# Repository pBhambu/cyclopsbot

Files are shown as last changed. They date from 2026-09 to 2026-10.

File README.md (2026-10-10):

# Cyclops Bot

An ESP32-powered robotics project controlled via Bluetooth Low Energy (BLE) using an Xbox Series X/S controller. Cyclops Bot features multi-servo continuous sweeping controls, an OLED display with custom animated face graphics, and dedicated PCB pin architecture.


robotthumnail

---

## Overview
Cyclops Bot uses an ESP32 microcontroller with an Xbox Series X/S controller over BLE using the XboxSeriesXControllerESP32_asukiaaa library. It translates controller inputs (triggers, bumpers, and buttons) into smooth position updates across 8 independent servo channels while maintaining an expressive OLED display interface.

### Key Features
- **BLE Wireless Control:** Connects to Xbox Series X/S controllers without dongles.
- **Smooth Sweep Engine:** Uses non-blocking position updates to provide smooth, continuous servo sweeps.
- **Multi-Servo Support:** Drives up to 8 independent servos with preset angle bounds and default stances.
- **Dedicated Custom PCB:** Integrates power regulation, signal breakout headers, and I2C lines directly on a custom carrier board.
- **Expressive OLED Interface:** Displays an animated eye on an I2C SSD1306 display.

---

## Hardware Architecture & Custom PCB

Cyclops Bot utilizes a custom printed circuit board (PCB) designed to consolidate component connections, isolate heavy motor current loads, and eliminate loose jumper wiring.

pcbpic

### PCB Hardware Specifications
- **Microcontroller Socket:** Dual header pins designed to fit standard 30-pin ESP32 Dev Module footprint.
- **Servo Header Rail (H1–H8):** 8 sets of 3-pin male headers (GND, VCC, Signal) wired directly to dedicated ESP32 GPIOs.
- **Power Separation Plane:** Isolated high-current 5V bus powering the servo headers separately from the ESP32 logic power rail.
- **Display Terminal:** 4-pin I2C breakout header providing 3.3V/5V, GND, SDA (GPIO 21), and SCL (GPIO 22).

---

## Components Required

### Microcontroller & Display
- **ESP32 Development Board** (e.g., ESP32 Dev Module)
- **Cyclops Bot Custom PCB**  (or breadboard/protoboard with wires)
- **0.96" SSD1306 OLED Display** (128x64 pixels, I2C interface)

### Actuators & Power
- **8x Micro Servos** (e.g., SG90, MG90S, or similar 5V servos)
- **External 5V DC Power Supply** (Minimum 3A recommended to handle servo stall currents)

### Controller
- **Xbox Series X/S Wireless Controller** (Updated with standard BLE firmware, non-controller option available)

---

## Wiring & Pin Mapping

> **Important:** Never power 8 servos directly from the ESP32's 3.3V or 5V pins. Always route the external 5V power supply to the PCB's main power screw terminal or power jack.

### Servo Pin Assignments

| PCB Servo Header | Target Motor | ESP32 GPIO Pin |
| :--- | :--- | :--- |
| **H1** | Motor 1 | **GPIO 13** |  
| **H2** | Motor 2 | **GPIO 12** | 
| **H3** | Motor 3 | **GPIO 27** | 
| **H4** | Motor 4 | **GPIO 14** | 
| **H5** | Motor 5 | **GPIO 26** |
| **H6** | Motor 6 | **GPIO 25** |
| **H7** | Motor 7 | **GPIO 33** | 
| **H8** | Motor 8 | **GPIO 32** |

### OLED Display Pin Assignments (I2C)

| SSD1306 Pin | PCB Header / ESP32 GPIO Pin |
| :--- | :--- |
| **VCC** | 3.3V / 5V Rail |
| **GND** | Common GND Plane |
| **SDA** | **GPIO 21** |
| **SCL** | **GPIO 22** |

---
## Xbox Controller Mappings

| Control Input | Action / Motion |
| :--- | :--- |
| **Left Joystick (Forward)** | Move Forward |
| **Left Joystick (Backwards)** | Move Backwards |
| **Left Joystick (Left / Right)** | Move Sideways |
| **Hold RT (Right Trigger)** | Rotate Front Right |
| **Hold RB (Right Bumper)** | Rotate Back Right |
| **Hold LT (Left Trigger)** | Rotate Front Left |
| **Hold LB (Left Bumper)** | Rotate Back Left |
| **Button A** | Attention Stance/wave|
| **Button B** | Sleep animation |

## Setup & Installation Instructions

### 1. Software Requirements
Ensure you have the **Arduino IDE** installed along with the ESP32 board package (`esp32` by Espressif Systems).

### 2. Install Required Libraries
Open the **Library Manager** in Arduino IDE (`Tools` -> `Manage Libraries...`) and install the following:

- **ESP32Servo** by Kevin Harrington
- **Adafruit_GFX** by Adafruit
- **Adafruit_SSD1306** by Adafruit
- **XboxSeriesXControllerESP32_asukiaaa** by Asuki Kono

### 3. Board & IDE Settings
Select your board configuration under **Tools**:
- **Board:** ESP32 Dev Module or similar
- **Upload Speed:** 115200

### 4. Upload & Pairing Procedure
1. Connect your ESP32 to your computer via USB and upload the sketch.
2. Open the **Serial Monitor** set to **115200 baud**.
3. Turn on your Xbox controller and hold the **Pairing Button** on top until the Xbox symbol flashes rapidly.
4. Keep the controller within close proximity to the ESP32. The Xbox button light will turn solid once successfully paired.

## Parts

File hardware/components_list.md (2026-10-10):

# Cyclops Bot Hardware - Bill of Materials (BOM)

This document details the complete hardware component list required to build and assemble the **Cyclops Bot**.

---

## Component List
For best quality and the shortest shipping time, Amazon is the best option. If you are willing to wait longer for shipping, use AliExpress or another trustworthy seller.
| Component | Category | Quantity | Notes |
| :--- | :--- | :--- | :--- |
| **ESP32 Microcontroller** | Microcontroller | 1 | ESP32 Dev Module or compatible board |
| **Servo Motors** | Actuators | 8 | SG90, MG90S, or similar 5V micro servos |
| **OLED Screen** | Display | 1 | 0.96 inch SSD1306 128x64 I2C display |
| **KCD1 Rocker Switch** | Power / Switch | 1 | Main power control switch |
| **Step-Down Converter** | Power | 1 | Buck regulator steps voltage down to stable 5V output |
| **Male Header Pins** | Connectors | 1 | 2.54mm pitch strip for PCB headers |
| **LiPo Battery** | Power | 1 | Main power source |
| **XT30 Pigtail Connector** | Power / Connectors | 1 | Male/Female battery connector lead |
| **Custom PCB** | Electronics | 1 | Cyclops Bot carrier circuit board |
| **Screws & Fasteners** | Hardware | TBD | Specific sizes and counts to be updated |

---

## Assembly Notes

- **Power Architecture:** Always ensure the **Step-Down Converter** is adjusted to output a stable **5V** before connecting it to the custom PCB or servos.
- **Header Pin Soldering:** Solder male header pins onto the PCB for all 8 servo channels (`H1` through `H8`) and the OLED display interface before mounting the ESP32.

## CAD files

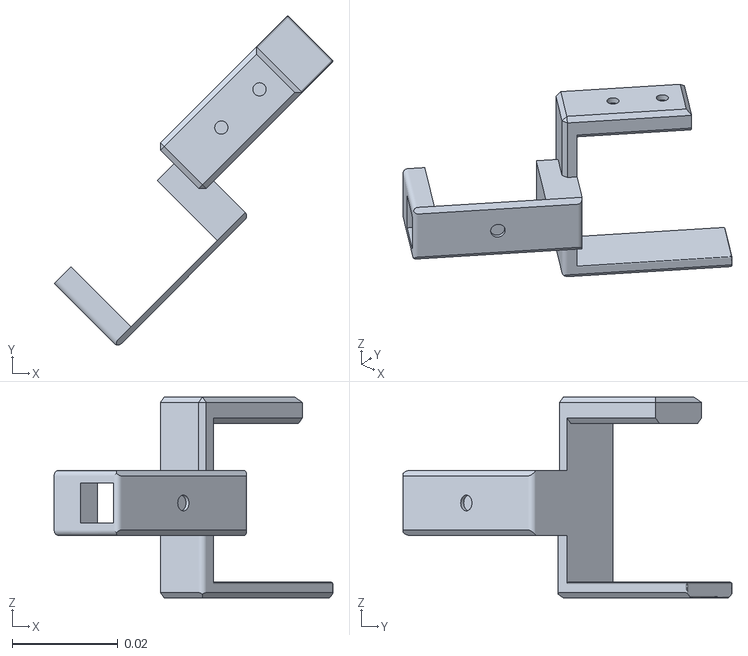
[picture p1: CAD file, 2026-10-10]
hardware/stlFiles/joint.stl
0.0526 x 0.0621 x 0.0379

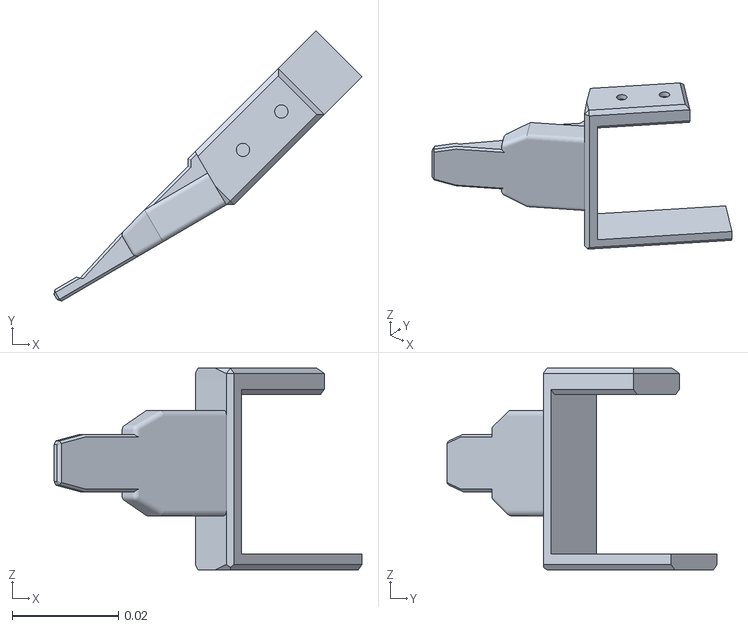
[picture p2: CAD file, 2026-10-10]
hardware/stlFiles/leg.stl
0.0579 x 0.0508 x 0.0379

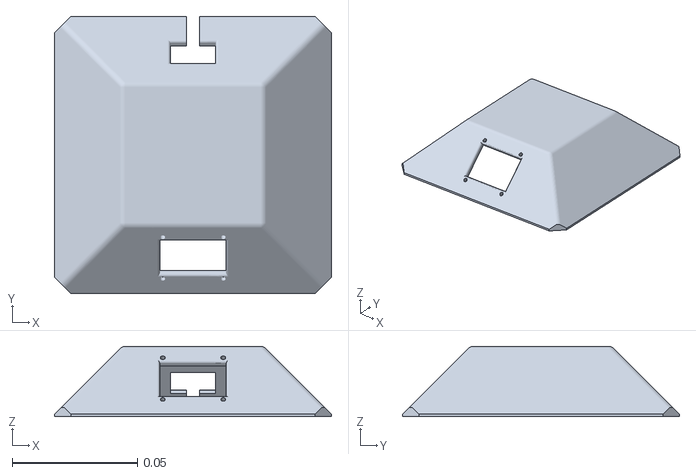
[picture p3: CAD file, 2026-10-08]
hardware/stlFiles/cover.stl
0.111 x 0.111 x 0.028

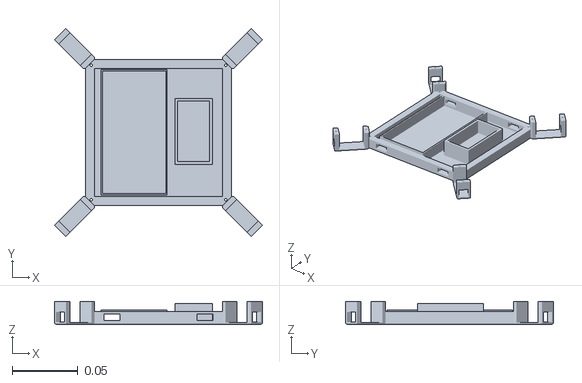
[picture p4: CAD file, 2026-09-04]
hardware/stlFiles/frame.stl
0.158 x 0.158 x 0.0177

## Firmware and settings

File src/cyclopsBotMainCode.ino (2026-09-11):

#include <Wire.h>
#include <Adafruit_GFX.h>
#include <Adafruit_SSD1306.h>
#include <ESP32Servo.h>
#include <XboxSeriesXControllerESP32_asukiaaa.hpp>

// --- OLED Setup ---
#define SCREEN_WIDTH 128
#define SCREEN_HEIGHT 64
#define OLED_RESET    -1
Adafruit_SSD1306 display(SCREEN_WIDTH, SCREEN_HEIGHT, &Wire, OLED_RESET);

const int EYE_X = 64;
const int EYE_Y = 32;

// --- ESP32 GPIO Pin Assignments ---
const int PIN_R1 = 13; // Hip Front Right
const int PIN_R2 = 12; // Hip Back Right
const int PIN_L1 = 27; // Hip Front Left
const int PIN_L2 = 14; // Hip Back Left

const int PIN_R3 = 26; // Lift Front Right
const int PIN_R4 = 25; // Lift Back Right
const int PIN_L3 = 33; // Lift Front Left
const int PIN_L4 = 32; // Lift Back Left

// --- Servo Objects ---
Servo servoR1, servoR2, servoL1, servoL2;
Servo servoR3, servoR4, servoL3, servoL4;

// --- Controller Instance ---
XboxSeriesXControllerESP32_asukiaaa::Core xboxController;

// --- Gait Parameters ---
int stepState = 0;
unsigned long lastStepTime = 0;
const int STEP_DELAY = 120; // Step speed (ms)
bool isStanding = true;

// --- OLED Cyclops Eye Renderer ---
void drawCyclopsEye(int pupilOffsetX = 0, int pupilOffsetY = 0) {
  display.clearDisplay();

  // Outer Eye White Area (Sclera)
  display.fillCircle(EYE_X, EYE_Y, 28, SSD1306_WHITE);

  // Eyelid Cutouts
  display.fillRect(EYE_X - 40, EYE_Y - 45, 80, 25, SSD1306_BLACK);
  display.fillRect(EYE_X - 40, EYE_Y + 20, 80, 25, SSD1306_BLACK);

  // Eyelid Outlines
  display.drawFastHLine(EYE_X - 30, EYE_Y - 18, 60, SSD1306_BLACK);
  display.drawFastHLine(EYE_X - 30, EYE_Y + 18, 60, SSD1306_BLACK);

  // Iris Outer Ring
  display.fillCircle(EYE_X + pupilOffsetX, EYE_Y + pupilOffsetY, 16, SSD1306_BLACK);
  display.drawCircle(EYE_X + pupilOffsetX, EYE_Y + pupilOffsetY, 17, SSD1306_WHITE);

  // Pupil Center
  display.fillCircle(EYE_X + pupilOffsetX, EYE_Y + pupilOffsetY, 10, SSD1306_WHITE);
  display.fillCircle(EYE_X + pupilOffsetX, EYE_Y + pupilOffsetY, 8, SSD1306_BLACK);

  // Catchlight Glint
  display.fillRect(EYE_X + pupilOffsetX - 4, EYE_Y + pupilOffsetY - 5, 3, 3, SSD1306_WHITE);

  display.display();
}

// --- Default Stances ---
void standUp() {
  // Hips to Neutral (Side - 90°)
  servoR1.write(90);
  servoR2.write(90);
  servoL1.write(90);
  servoL2.write(90);

  // Lifts facing DOWN
  servoR3.write(180); // R3 Down
  servoR4.write(0);   // R4 Down
  servoL3.write(0);   // L3 Down
  servoL4.write(180); // L4 Down
  
  isStanding = true;
  drawCyclopsEye(0, 0);
}

void layDown() {
  // Lift legs UP flat
  servoR3.write(0);   // R3 Up
  servoR4.write(180); // R4 Up
  servoL3.write(180); // L3 Up
  servoL4.write(0);   // L4 Up

  isStanding = false;
  drawCyclopsEye(0, 4); // Eye looks down when laying down
}

// --- Action & Emote Routines ---
void performWave() {
  // Raise Front Right Lift Leg
  servoR3.write(0); 
  drawCyclopsEye(6, -4);
  delay(200);

  // Wave Front Right Hip back and forth
  for (int i = 0; i < 3; i++) {
    servoR1.write(135);
    delay(150);
    servoR1.write(45);
    delay(150);
  }

  // Return to Stand
  standUp();
}

void performDiagonalDance() { // Button X
  for (int i = 0; i < 2; i++) {
    // Step 1: Front Right (R3) & Back Left (L4) spin UP
    servoR3.write(0);   
    servoL4.write(0);   
    drawCyclopsEye(-6, -4);
    delay(200);

    // Return to Down
    servoR3.write(180); 
    servoL4.write(180); 
    delay(200);

    // Step 2: Front Left (L3) & Back Right (R4) spin UP
    servoL3.write(180); 
    servoR4.write(180); 
    drawCyclopsEye(6, -4);
    delay(200);

    // Return to Down
    servoL3.write(0);   
    servoR4.write(0);   
    delay(200);
  }
  standUp();
}

void performTwistWiggle() { // Button Y
  // Twist hips left and right while keeping lifts grounded
  for (int i = 0; i < 3; i++) {
    // Twist body Left
    servoR1.write(120);
    servoR2.write(120);
    servoL1.write(120);
    servoL2.write(120);
    drawCyclopsEye(-8, 0);
    delay(150);

    // Twist body Right
    servoR1.write(60);
    servoR2.write(60);
    servoL1.write(60);
    servoL2.write(60);
    drawCyclopsEye(8, 0);
    delay(150);
  }
  standUp();
}

void walkForwardStep() {
  switch (stepState) {
    case 0:
      servoR3.write(45);  
      servoL4.write(45);  
      break;
    case 1:
      servoR1.write(135); 
      servoL2.write(45);   
      servoL1.write(135);  
      servoR2.write(45);  
      break;
    case 2:
      servoR3.write(180);  
      servoL4.write(180);  
      break;
    case 3:
      servoR4.write(135); 
      servoL3.write(135); 
      break;
    case 4:
      servoL1.write(45);  
      servoR2.write(135);  
      servoR1.write(45);  
      servoL2.write(135); 
      break;
    case 5:
      servoR4.write(0);  
      servoL3.write(0);  
      break;
  }
  stepState = (stepState + 1) % 6;
}

void setup() {
  Serial.begin(115200);

  // Initialize OLED
  Wire.begin(21, 22);
  if (display.begin(SSD1306_SWITCHCAPVCC, 0x3C)) {
    drawCyclopsEye(0, 0);
  }

  // Attach Servos
  servoR1.attach(PIN_R1, 500, 2400);
  servoR2.attach(PIN_R2, 500, 2400);
  servoL1.attach(PIN_L1, 500, 2400);
  servoL2.attach(PIN_L2, 500, 2400);

  servoR3.attach(PIN_R3, 500, 2400);
  servoR4.attach(PIN_R4, 500, 2400);
  servoL3.attach(PIN_L3, 500, 2400);
  servoL4.attach(PIN_L4, 500, 2400);

  standUp();
  xboxController.begin();
}

void loop() {
  xboxController.onLoop();

  if (xboxController.isConnected()) {
    // Reading Inputs
    uint16_t joyY = xboxController.xboxNotif.joyLVert;
    bool btnA = xboxController.xboxNotif.btnA;
    bool btnB = xboxController.xboxNotif.btnB;
    bool btnX = xboxController.xboxNotif.btnX;
    bool btnY = xboxController.xboxNotif.btnY;

    bool trigRT = xboxController.xboxNotif.trigRT > 100;
    bool trigLT = xboxController.xboxNotif.trigLT > 100;
    bool btnRB  = xboxController.xboxNotif.btnRB;
    bool btnLB  = xboxController.xboxNotif.btnLB;

    // --- Button Actions ---
    if (btnA) {
      if (!isStanding) {
        standUp();
      } else {
        performWave();
      }
      delay(300);
    } 
    else if (btnB) {
      if (isStanding) {
        layDown();
      } else {
        // Rotate legs up and down once if already down
        servoR3.write(180); servoR4.write(0); servoL3.write(0); servoL4.write(180);
        delay(300);
        layDown();
      }
      delay(300);
    } 
    else if (btnX) {
      performDiagonalDance();
      delay(300);
    } 
    else if (btnY) {
      performTwistWiggle();
      delay(300);
    }

    // --- Manual Individual Leg Rotation Triggers ---
    else if (trigRT) { servoR1.write(135); } // Rotate Front Right Hip
    else if (trigLT) { servoL1.write(45);  } // Rotate Front Left Hip
    else if (btnRB)  { servoR2.write(135); } // Rotate Back Right Hip
    else if (btnLB)  { servoL2.write(45);  } // Rotate Back Left Hip

    // --- Walking Gait Control ---
    else if (joyY > 40000) {
      if (millis() - lastStepTime > STEP_DELAY) {
        walkForwardStep();
        drawCyclopsEye(0, -4);
        lastStepTime = millis();
      }
    } 
    else {
      // Auto Reset to Stand Stance when idle
      if (stepState != 0) {
        standUp();
        stepState = 0;
      }
    }
  }

  vTaskDelay(10 / portTICK_PERIOD_MS);
}

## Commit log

2026-08-30 Update and rename components_list.csv to components_list
    [components_list.csv]
2026-09-04 Create frame
2026-10-12 Create wiring
2026-10-13 Update and rename wiring to wiring.md
